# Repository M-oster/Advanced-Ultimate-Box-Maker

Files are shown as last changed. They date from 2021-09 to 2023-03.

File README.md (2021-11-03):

# Advanced Ultimate-Box-Maker

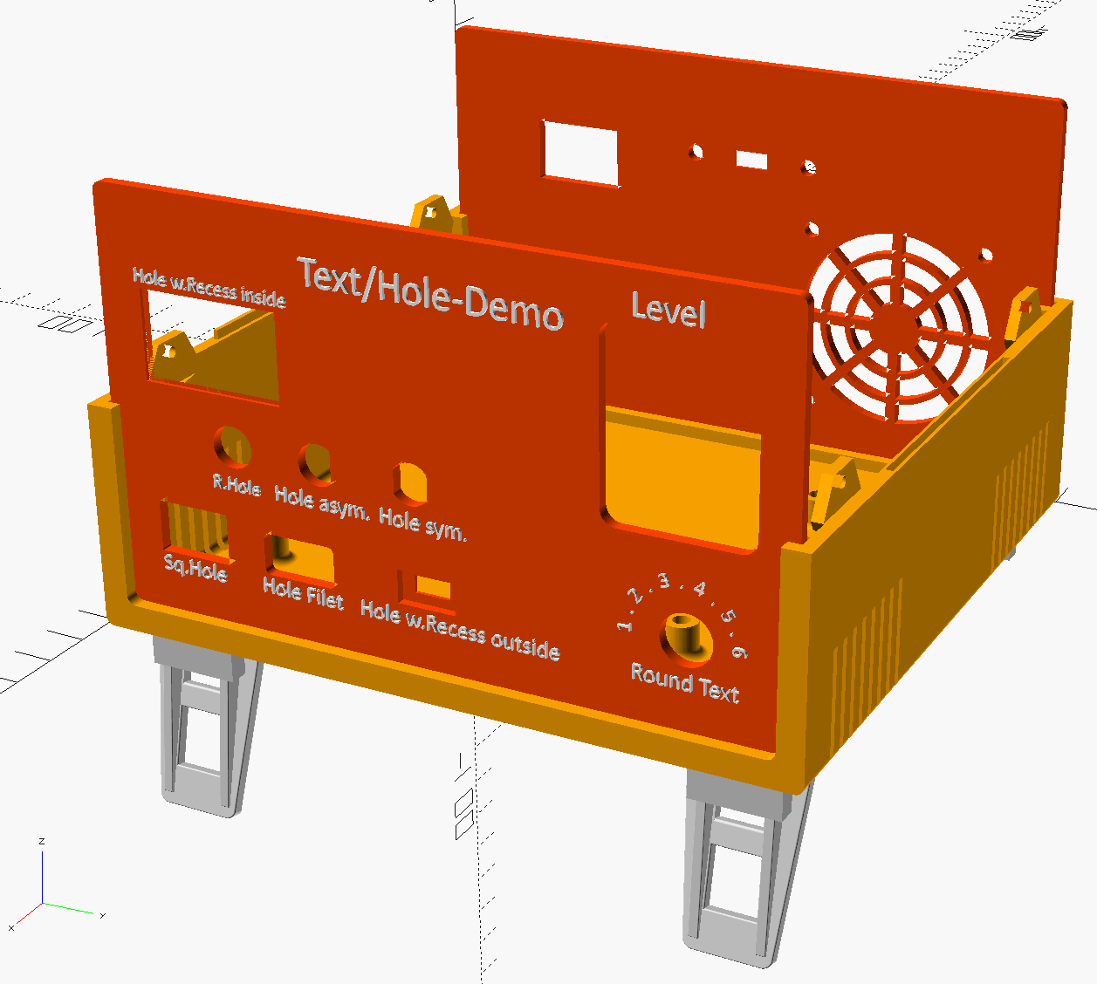
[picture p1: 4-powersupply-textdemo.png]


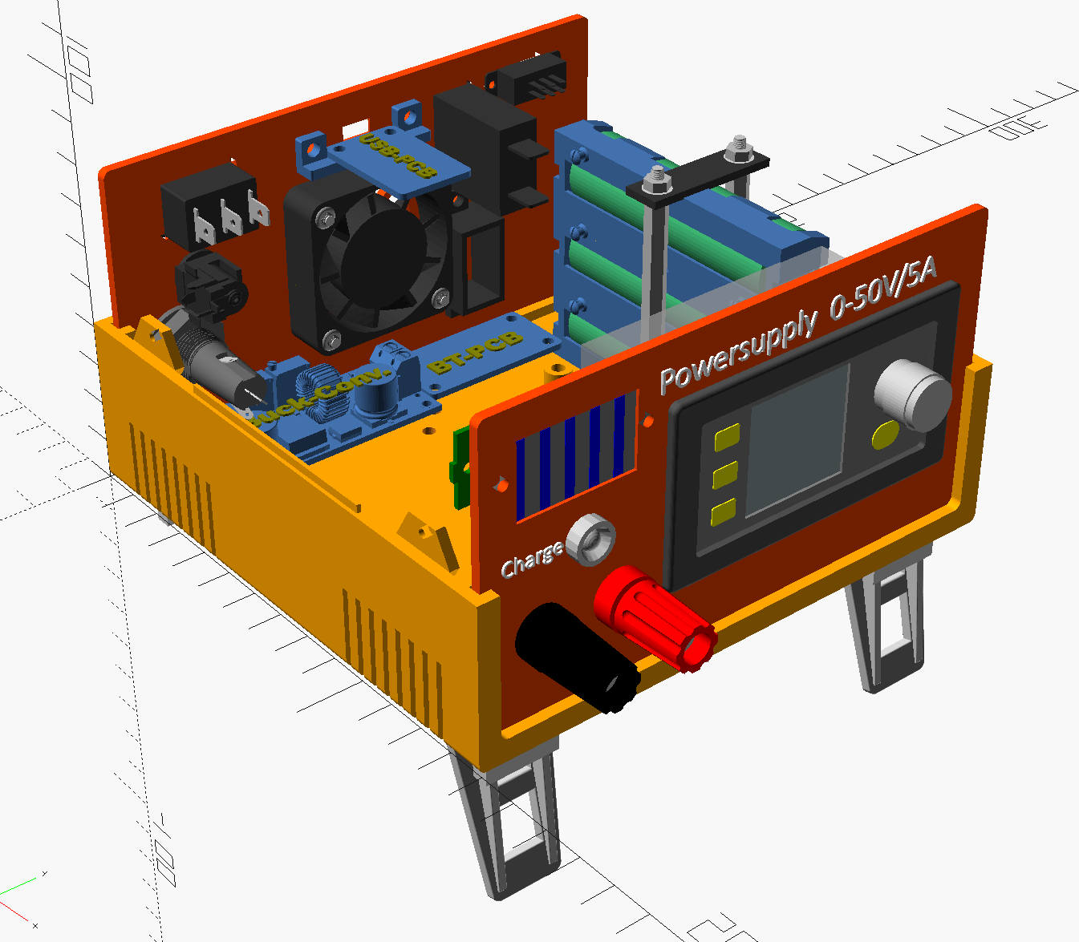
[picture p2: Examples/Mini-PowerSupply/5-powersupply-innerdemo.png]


## Introduction
For my projects in electronics I often need an appropriate housing. 
Commercial products have the disadvantage that they don’t fit exactly and cause a lot of work for manual drilling, cutting, adapting, etc.
I needed a software solution for creating an individual box using a 3D-printer.
* The software must have mainly a parametric design so that the properties of the box can be easily changed.
* The software must have a GUI for changing the parameters so that the program code does not need to be changed.
* Ideally the software allows to save the parameters in individual files.
* The software with the less disadvantages I could find, was OpenSCAD.
It is relatively easy to learn and has a so called customizer for changing and saving the parameters. But it has also a lot of restrictions to deal with. Despite this OpenSCAD was the first choice. My normally used CAD-Software “Fusion-360” is nice to use but has only a bit of a customizer.

For that reason, the decision was using OpenSCAD and I searched around which programs exists to solve my problem.
I found the “Ultimate Box Maker” with its forks and put me on to extend the features of these programs with help of some excellent libraries.
The result is this “Advanced Ultimate Box Maker”.

## Sources used in this advanced version
Originally box designs, used libraries and license
*	The original design was made by “Ultimate Box Maker” from Heartman www.thingiverse.com/thing:1264391 and http://heartygfx.blogspot.com
*	Great improvement to a PCB-based construction was made with the “Customizable revised Ultimate Box Maker”` from jbebel www.thingiverse.com/thing:2938921 and https://github.com/jbebel/Ultimate-Box-Maker.
*	The integration of a fan-guard was inspired by the “Customizable Fan Grill Cover”  from mightynozzle www.thingiverse.com/thing:2802474
*	use of the Library “BOSL2” from https://github.com/revarbat/BOSL2/
*	use of the Library “NopSCADlib” from https://github.com/nophead/NopSCADlib/
* `Programs are under license CC BY-NC 3.0 License and GNU General Public License 3`

## Requirements
1. OpenSCAD, download it from here: https://www.openscad.org/downloads.html
2. The library “BOSL2” from https://github.com/revarbat/BOSL2/
3. The library “NopSCADlib” from https://github.com/nophead/NopSCADlib
4. The actually “Advanced ultimate Box Maker” from here or thingiverse https://www.thingiverse.com/thing:4947863

## Installation
*	run the downloaded OpenSCAD-file and install the exe.
*	unpack the zip-file form BOSL2-library into the appropriate lib-directory (My Documents\OpenSCAD\libraries)
*	do the same with library-file “NopSCADlib”
*	The actually “Advanced ultimate Box Maker” from here.
Unpack the zip-file into the directory My Documents\OpenSCAD so that all files are in the sub-directory \Advanced-Ultimate-Box-Maker.
You have to create the directories without the Extension "-master" which github adds to the zip-files.

For checking of the installation, run the main-file “Advanced-Ultimate-Box-Maker-main.scad”, and press F5 within the GUI to create the basic box.

## Directory structure
the directory structure is inspired by the one from NopSCADlib.
But the project creating features are not used here, because its too much effort in the moment to additionally extend and adapt the code.

| Path | Contents |
|:-----|:---|
| `assemblies` | additional parts which are used for the box |
| `docs` | Documentation files, Schematics |
| `Examples` | Example projects with its own directories|
| `scad` | main scad file and associated scad files |
| `stls` | STL files for making printed parts |

## Features
Summary of Existing Features from the original version and the improved version:
*	Editable back- and front panel
*	Calculation of the box size from the PCB size and margin parameters
*	Horizontal or vertical text alignment arguments
*	Variable panel and tab thickness separate from the box
*	Square corners (no filet or chamfer)
*	Parameterize all dimensions, such that the box is infinitely scalable. Doubling every parameter will double the box in all dimensions.
*	Vents go through the floor and are scaled to fit the size of the filet.
*	For larger filets, scale interior filets to make exterior and interior filets concentric.
*	Decorations are optional
*	Box fixation tabs can individually be placed on the top or bottom shell

## Added more features to this Advanced version, list of the most important ones:
*	Allows to integrate the electronic parts of the NopSCADlib
*	Choice of different case feet (Hole,integrated feet, Rubber feet, Foldable feet)
*	Choice of different threated inserts for fixation tabs
*	Choice of different kind of PCB-feet (inserts, pillars, spacers)
*	Holes with a recess for front- or backpanel
*	Longholes for front- or backpanel
*	Customizable fan-guard for the backpanel
*	a lot of fan-sizes are integrated and their correct screw-distance is autom. choosen.
*	Ledges on both upper edges of the box shells for better stabilization
*	Allows to create extra holes in the bottom shell
*	Choose predefined textfont for paneltext
*	Frequent remarks added in the code and a lot of debug outputs can be activted

With this advanced version the number of program lines has grown from round about 900 to over 1800 lines.

## Handling the program
After starting OpenSCAD, you see the customizer on the right side with the various program values categorized in sections.
Click the center symbol   to view the hole box

### Sections and values
Sections and values in the customizer on the right windows side of the program:
These sections include several parametric values to adapt the box to the requirements in an easy way
and are generated from the appropriate code on the left side of the editor window.

### Different kind of values in the customizer
| Value | Description |
|:---|:---|
|Arrays, expression begins with “a..”|Cannot be changed in customizer.MUST be changed in the editor window on the left because of the customizers restrictions.
|Textbox| sets a text f.e.Front- or Backpanel. Change in customizer|
|Boolean Value|activates/deactivates an option. Change in customizer|
|Select field|selects a value out of a given list|
|Numeric value|can be changed in customizer|
All values, with exception of the arrays, can be saved in a configuration-file on top of the customizer window. The arrays must be saved with the complete scad-file (i.e. changing of the code)
 
One member in an array is the minimum, otherwise the program throws an error.
If the part is not used, array-members can be deactivated when On/Off-value is set to “0”.

### The most important values:
#### Section “box options”
| Section | Description |Remark|
|:---|:---|:---|
|PCBDraw| draws the PCB inside the box, labels it with text of “TextOnPCB”|	Array must be edited in code window.|
|aAddHoles|For adding holes in the bottom shell| for additional PCBs f.e.|
|PartsDraw|Draws electr. Parts with help of the NopSCADlib.| Parts must be imported and positioned in Module “ShowElectrParts”|
|Bar recess|Small ledge on top of Shells, can be activated/deactivated. |When Thick <2.5mm, recess is autom. deactivated because it cannot be printed|
|sTextFonts|Selection of the font for text on panels.| List contains windows-fonts and can be changed in code window. Font names must fit to the name in windows.|

#### Section “case feet”
| Section | Description |Remark|
|:---|:---|:---|
|CaseFeet|Various feet can be chosen (simple hole, Rubber feet, Foldable feet in 2 sizes)| The last both are created as stl-files and can be 3D-printed.|

#### Section “Box Fixation Tabs”
| Section | Description |Remark|
|:---|:---|:---|
|tab_inserts|Various kinds of fixations| simple holes for screws, threaded inserts|

#### Section “PCB Options”
With defining these variables the dimensions of the box are autom. calculated.
The value “TopMargin” defines in result the hight of the box.
The console window shows the result of the dimensions of the box.

#### Section “PCB Feet”
| Section | Description |Remark|
|:---|:---|:---|
|PCBFeet|Various kinds of PCB-feet, from simple holes for screws to holes with threaded inserts| All dimensions are autom. adapted|
Coordinates of the 4 PCB-feet:	The console window shows the resulting distances of the PCB-feet to prove the correct values of the PCB-holes.
If you enable “ShowExplanations” in the section ”Special Values”, the console window shows the position of the 4 PCB-feet.

#### Section “Frontplate Holes”
The variables within this section define 3 kind of holes. 
All these hole-parameters are Arrays and must be changed in the code window, not in the customizer.
| Section | Description |Remark|
|:---|:---|:---|
|aFP_Holes|	Defines round holes or longholes|There are 2 diams, diam1 and diam2. If both are equal, the result is a round hole. If diam1 > diam2 the result is a longhole,If sym=0, the hole is narrower on the right side.If sym=1, the hole is narrow on left ans right side|
|aFP_Sholes|Defines square holes
|aFP_SHolesRecess| 	Defines a recess of (PanelThick - Recess)|If Recess is positiv, its on the outer side. If recess is negativ, its on the inner side.

#### Section “Frontplate Text”
There are 2 kind of Texts. Normal text and round text.
All these hole-parameters are Arrays and must be changed in the code window, not in the customizer.
| Section | Description |Remark|
|:---|:---|:---|
|aFP_RTexts|	Defines round round text.| Useful for labeling Poti-values|
|aFP_STexts|	Defines normal text|

#### Section “Backplate Holes”, same as for Frontplate Holes

#### Section “Backplate Text”, same as for Frontplate Text

#### Section “Fan-guard settings”, only implemented for the Backplate
| Section | Description |Remark|
|:---|:---|:---|
|BP_fan_position|	Pos. of the fan-guard|can be activated by On/off-value set to “1”|
|Fan_size_in_mm|	List of fans are integrated in an array| When selecting a size, all parameters are calculated autom.|
|Screw_hole_diameter|	Diameter of the Fan-screw| M2, M3 or M4
|Fan_min_border_size|	The best fitting values are predefined.| Change them carefully|
|Fan_line_size| Size of pattern lines
|Fan_line_space| Space between two lines of the inner pattern	
|Number_of_support_lines|	Number of crosshairs for the fan-guard| 4 is a good value

#### Section “STL-element to export”
These Boolean values determine which part should be printed. `It makes sense to enable only one part.`
With keys F5, then F6, you can render a part for STL-Export.
Export the part with key F7 and save it as STL-file.
| Section | Description |Remark|
|:---|:---|:---|
|TShell|	Top shell of the box|
|BShell|	Bottom shell of the box|
|FPanl|	 Frontpanel|
|BPanel| Backpanel|
|SmallParts|Small assembly-parts which should be printed|It depends what you have choosen, f.e. can be spacers for the PCB.

#### Section “Special values”
| Section | Description |Remark|
|:---|:---|:---|
|ShowExplanations|	Self defined echo-outputs in the console-window|They are defined in the “MyExplanations.scad” file. f.e.the position of the 4 PCB-feet
|Debug|	When “1”, there is a lot of echo output from program-values|For easier assignment, the output has prefixed.<mod.>: from which module the output comes.<decription>: name of the variable or its description

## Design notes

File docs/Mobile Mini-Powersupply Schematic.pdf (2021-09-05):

Module view of the Powersupply

## Module view of the Powersupply

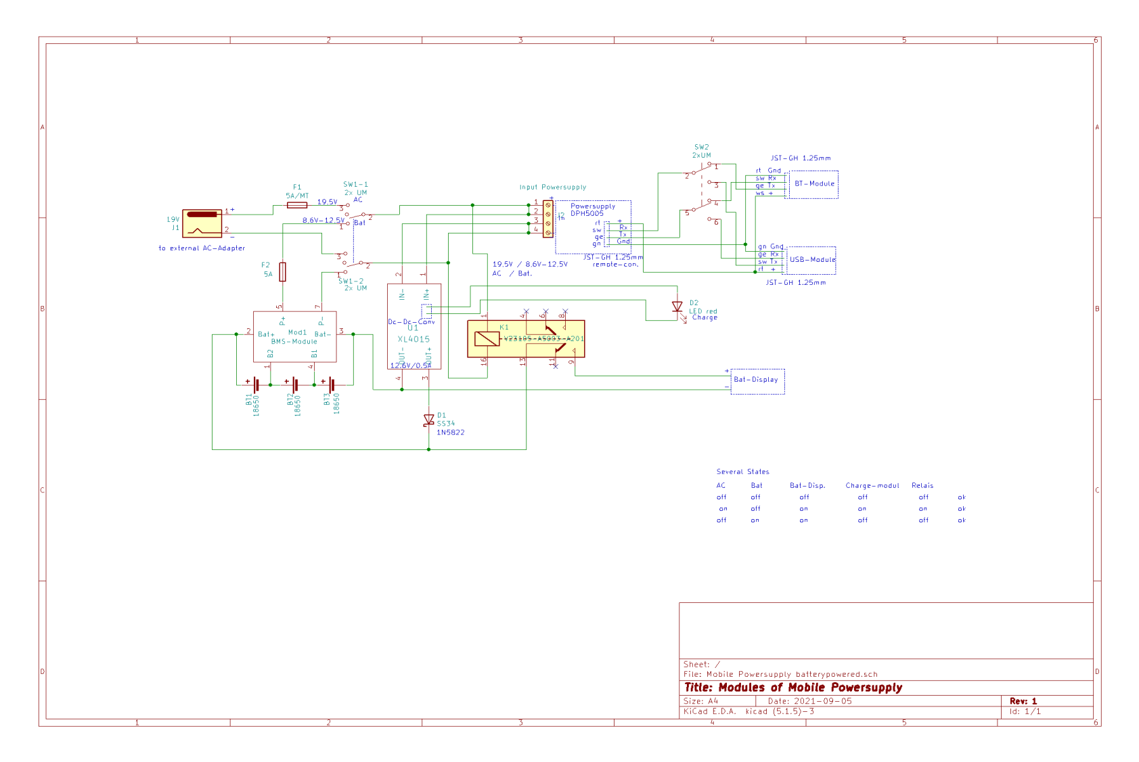
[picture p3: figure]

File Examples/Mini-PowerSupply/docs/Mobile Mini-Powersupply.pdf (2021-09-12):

# Mobile Mini-Powersupply

# Electronic

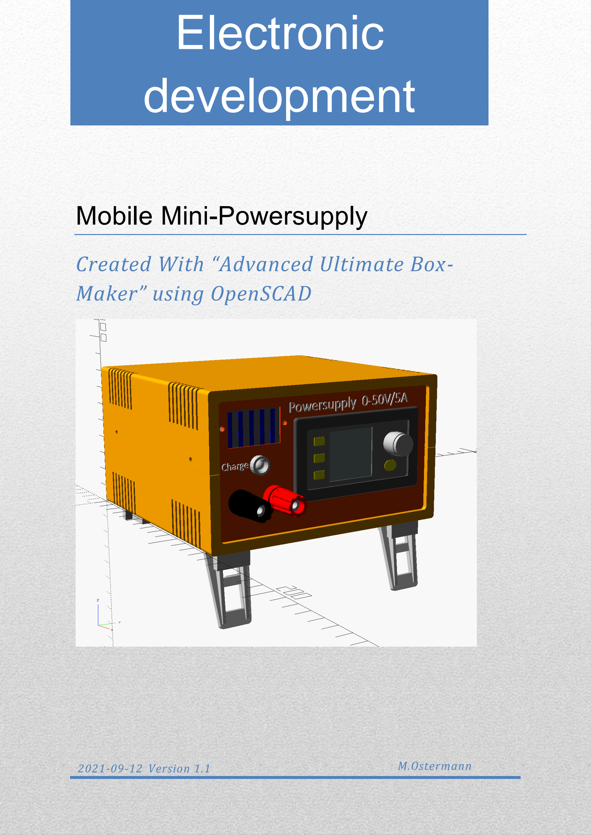
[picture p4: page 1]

Introduction

# Created With “Advanced Ultimate Box-Maker” using OpenSCAD

2021-09-12 Version 1.1

# development

M.Ostermann

# Mobile Mini-Powersupply

1

## Table of contents

Introduction | 0
Main design aspects of the DIY Powersupply | 0
The “Advanced Ultimate Box-Maker” with OpenSCAD | 0
Features of the Powersupply | 0
Explanation of the parts | 1
Buck-Boost converter DPH-5005 from Ruideng | 1
Li-ion charger module | 1
Protection module for batteries (BMS) | 1
AC-adapter with 19V / 4.5A | 1
3x Li-Ion battery cell 18650 | 1
Module view of the Powersupply | 0
Bill of Materials (BOM) | 0
Handling of the Powersupply | 0
The power switch | 0
Connections on the backside | 0
Additional work to do | 1
External LED for charge state | 1
Additional rubber feet for foldable feet | 1

Introduction

## Introduction

For my projects in electronics I often need an appropriate housing.
Commercial products have the disadvantage that they don’t fit exactly and cause a lot of work for manual drilling, cutting, adapting, etc.
I needed a software solution for creating an individual box using a 3D-printer.
- The software must have mainly a parametric design so that the properties of the box can be easily changed.
- The software must have a GUI for changing the parameters so that the program code does not need to be changed.
- Ideally the software allows to save the parameters in individual files.
The software with the less disadvantages I could find, was OpenSCAD.
It is relatively easy to learn and has a so called customizer for changing and saving the parameters. But it has also a lot of restrictions to deal with. Despite this OpenSCAD was the first choice. My normally used CAD-Software “Fusion-360” is nice to use but has only a bit of a customizer.

For that reason, the decision was using OpenSCAD and I searched around which programs to create boxes exists to solve my problem.

I found the “Ultimate Box Maker” with its forks and put me on to extend the features of these programs with help of some excellent libraries.
The result is this “Advanced Ultimate Box Maker”. (see the appropriate Docu)

Main design aspects of the DIY Powersupply
- The powersupply should be rather cheap and easy to build.
- It should consist of ready to use modules.
- Powersupply should be powered by chargeable batteries or external AC-adpater.

## The “Advanced Ultimate Box-Maker” with OpenSCAD

For Description of the features, the installation and how to use the software please read the paper “Advanced ultimate-Boxmaker”

Features of the Powersupply
- Outputvoltage 0-50V up to max.5A ( in AC-Mode)
- Constant current, Constant Voltage (CC, CV)
- Switchable operation between AC-Adapter and battery

Explanation of the parts

1

- Battery-Indicator
- Autom. battery charge during AC-operation
- Remote control over Bluetooth with smartphone app or USB PC-App

## Explanation of the parts

Buck-Boost converter DPH-5005 from Ruideng It is a ready-to-use kit from china. It has 4 modules:
- The converter itself
- the control-panel with the display
- Add. Consists of an USB-interface and
- Bluetooth-Interface for remote control of the powersupply.

Li-ion charger module
Charging module (3S) for charging the three 18650 cells during AC-mode. Charges the cells with 0.5A and has a charge cuttoff voltage of 12.6V.

Protection module for batteries (BMS)
This module protects the batteries in several manner:
- Overvoltage during charging
- Undervoltage during discharging
- Overcurrent protection for discharging

AC-adapter with 19V / 4.5A
The AC-adapter is switchable between 12V – 24V. 19V is the recommended voltage output.

3x Li-Ion battery cell 18650
Samsung INR18650-25R 2500mAh cells without protection

Module view of the Powersupply

## Module view of the Powersupply


Bill of Materials (BOM)

## Bill of Materials (BOM)

The parts are rather cheap and the source of supply is mostly in china and ebay
Description | | price
DPH5005 Buck-boost converter with USB- and BT-communication | https://de.aliexpress.com/item/32840324731.html without USB/BT-modules | 47€-40€
XL4015 5A DC-DC Step Down converter | https://www.ebay.de/itm/402597361624 or https://www.aliexpress.com/item/32891328430.html | 3,70€ or 2,30€
(270g/93m Filament 1.75mm PLA grey | | ~5,00€)
Axicom D2N12-960Relay DPDT (2xUM) V231005-A5003-A201 | Kessler electronic https://www.ebay.de/itm/111447113032 | 2,30€
BatteryIndicator LEDdisplay | Naltronic https://www.ebay.de/itm/123571387480?var=424142377263 or https://www.aliexpress.com/item/1005002375550407.html | 5,80€ or 2,80€
Battery-BMS, BalanceBoard, 6A-8A max Mesacomponents | https://www.ebay.de/itm/254159873534?var=553510124474 or https://www.aliexpress.com/item/4000385806747.html | 9,90€ or 2,30€
Switch On-off-on Wippschalter Ein-Aus-Ein | https://www.aliexpress.com/item/32967528231.html or https://www.ebay.de/itm/264813617899 | 2,20€ or 6,00€
Submini slide switch DPDT (Schiebeschalter 2xUM) | Kessler electronic https://www.ebay.de/itm/311859237255 | 1,00€
Powerplug High-Amp Switchcraft SC1943-ND | Digikey https://www.digikey.com/en/products/detail/switchcraft-inc/S1017/3909312 | 7,00€
Threated inserts M3x6g Gewindeeinsätze M3x6g (gegenläufig) | Msr-coptertools https://www.ebay.de/itm/173779404364 | 6,00€
Fuse-Holder Sicherungshalter Snapin SH8 | Centralsystems-isp https://www.ebay.de/itm/284368894849 | 3,55€
Fuse-Holder incl Si. 5A , 5x20mm, 12mm° | https://www.ebay.de/itm/173575874739 | 3,50€
Schottky-Diode 1N5822 | https://www.ebay.de/itm/254069873397 | 3,00€
Kfz-Flachsicherungen 10A | https://www.ebay.de/itm/233933295008 | 2,50€
Laptop AC-Adapter 12V-20V / 4.5A (19V-20V) | Flystorefly https://www.ebay.de/itm/402696857628 | 18,20€
Akkuhalter (Batteryholder) for 3 18650 cells | https://www.ebay.de/itm/174814565327 | 4,50€
Fan (Lüfter) 40mmx10mm, 5V, 2-pol | https://www.ebay.de/itm/384372531353 | 5,00€
LED with socket | https://www.ebay.de/itm/164496995162 | 2,75€
| Amount, (Summe) | 112€ -137€

Handling of the Powersupply

## Handling of the Powersupply

The power switch
The main power switch is on the backside and has three positions:
- the middle position is the off-postion. Powersupply is turned off.
- in postion “Bat” the device works in battery mode. It uses the internal battery-cells.

be careful, not to draw more than 4 A from the cells for a longer time. The batteries heat up and because battery socket is made of plastic, the contact springs expand. That will cause contact problems to the batteries.

To avoid this, you must use nickel stripes and a spot welder instead of sockets for connecting the batteries.
- In postion “AC” the external AC-Adapter must be connected. The batteries are autom. charged and the powersupply can deliver more current.
Batteries cannot be overcharged, the charge process is automatically completed.

Connections on the backside

Power switch Remote switch USB or BT Battery Fuse

USB for remote Ctrl

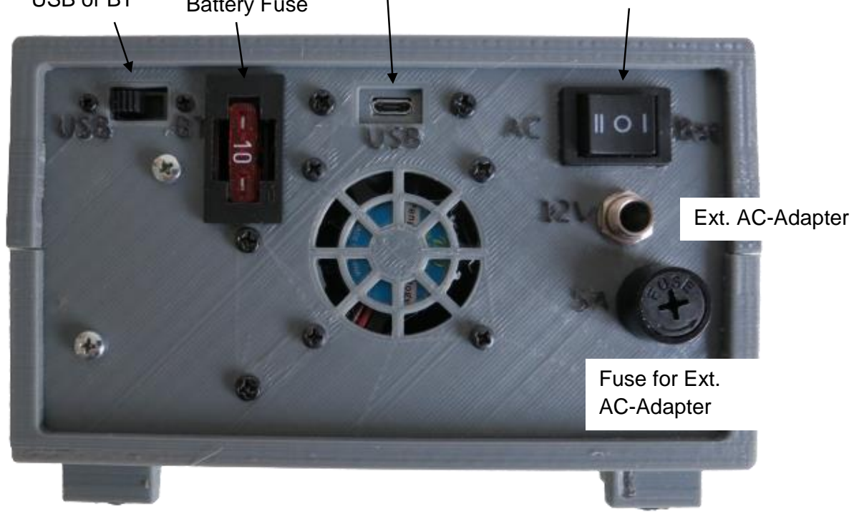
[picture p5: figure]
Ext. AC-Adapter; Fuse for Ext. AC-Adapter

Explanation of the parts

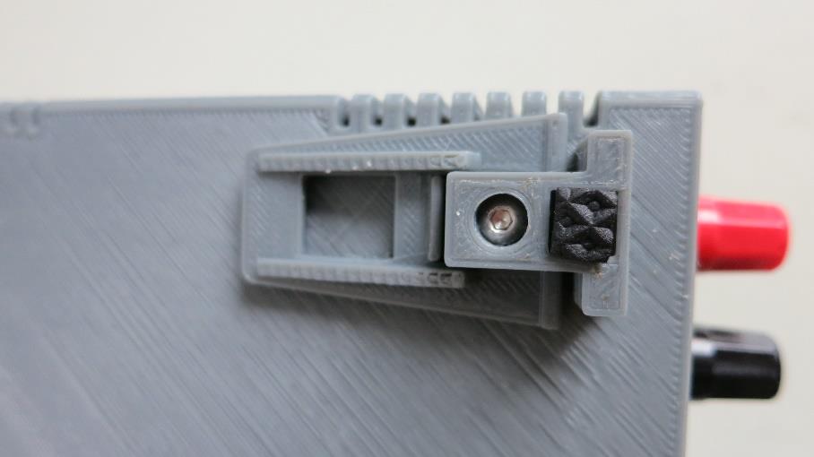
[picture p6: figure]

1

## Additional work to do

External LED for charge state
The small red LED on the PCB of the charge module ha to be desoldered for connecting the external LED.
Desolder the LED and solder two wires on the small pads.
On the other end solder these two wires to the external red LED.
Pay attention to the polarity of the LED. Don’t use another LED color.

Additional rubber feet for foldable feet
To prevent the powersupply form sliding over the ground the some rubber-feet can be added into the recess of the foldable feet.

But it must be self-adhesive rubber material not spongue rubber. That’s too soft.

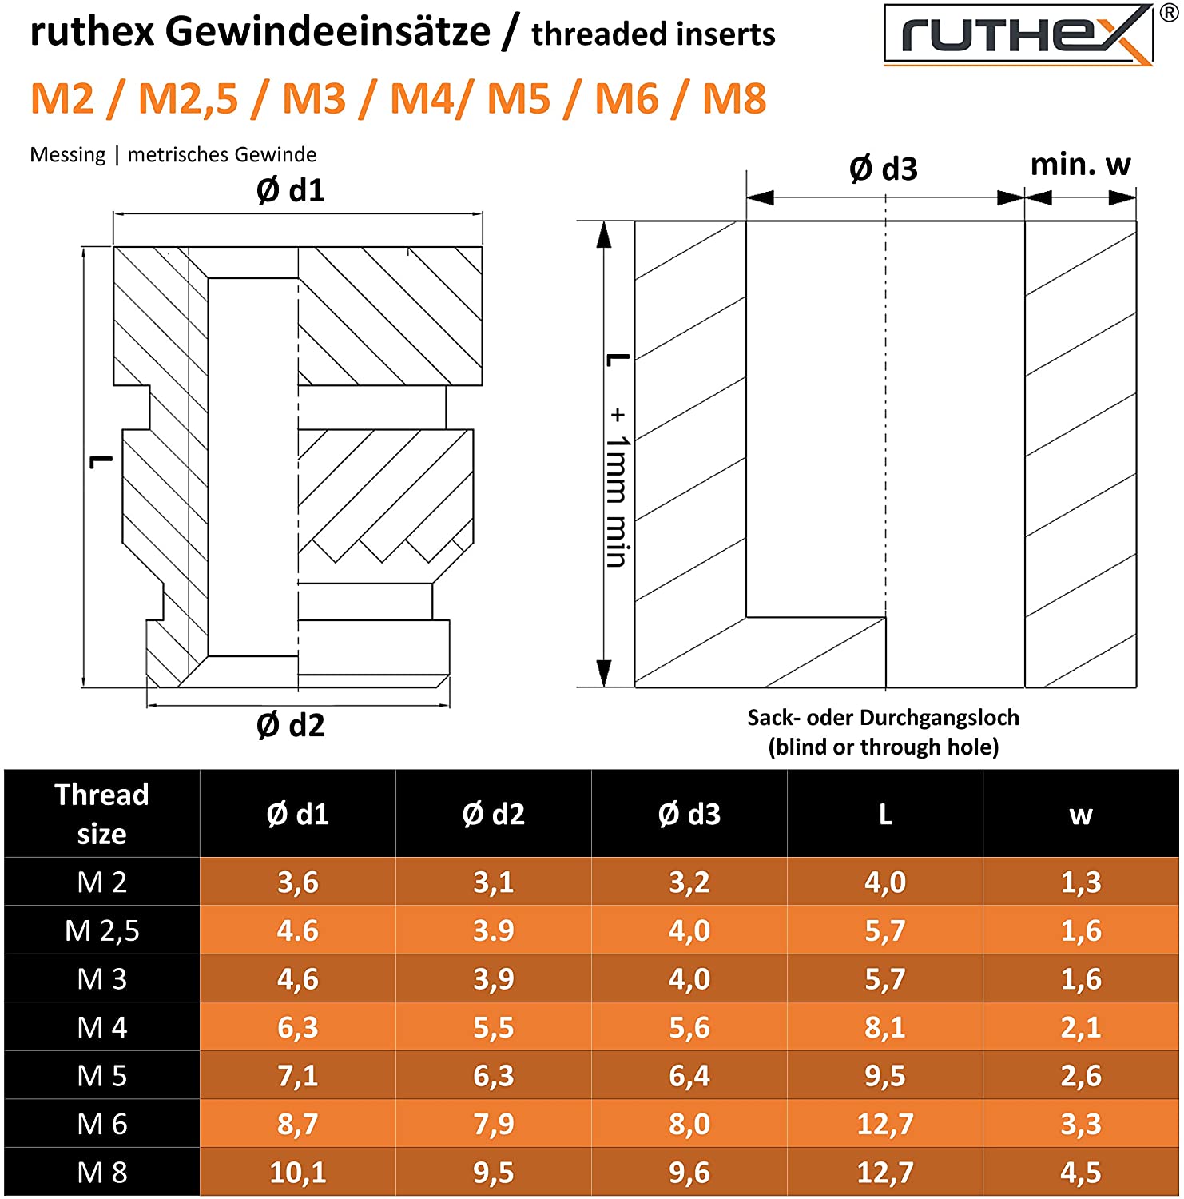
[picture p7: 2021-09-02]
Examples/Mini-PowerSupply/docs/Ruthex Inserts.jpg

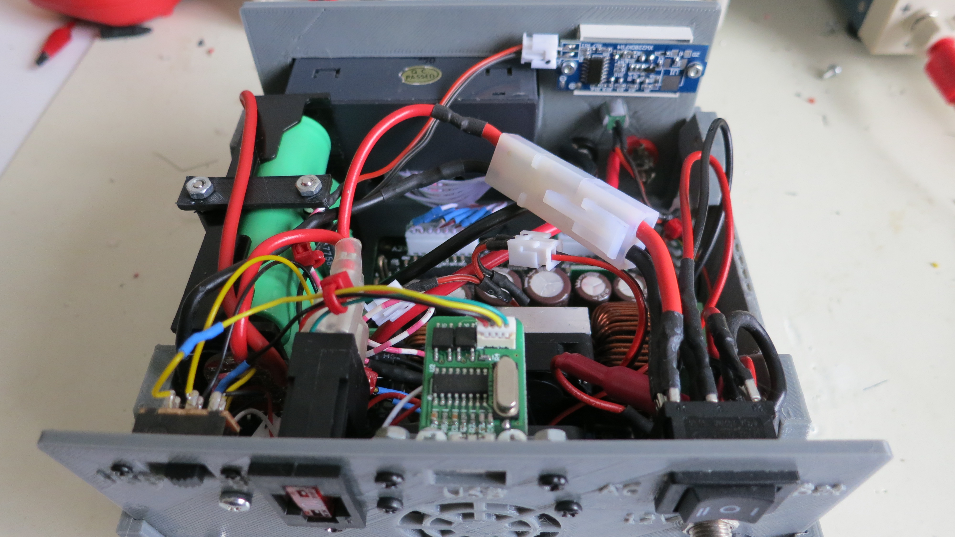
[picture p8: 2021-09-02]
Examples/Mini-PowerSupply/7-powersupply-innerview.JPG

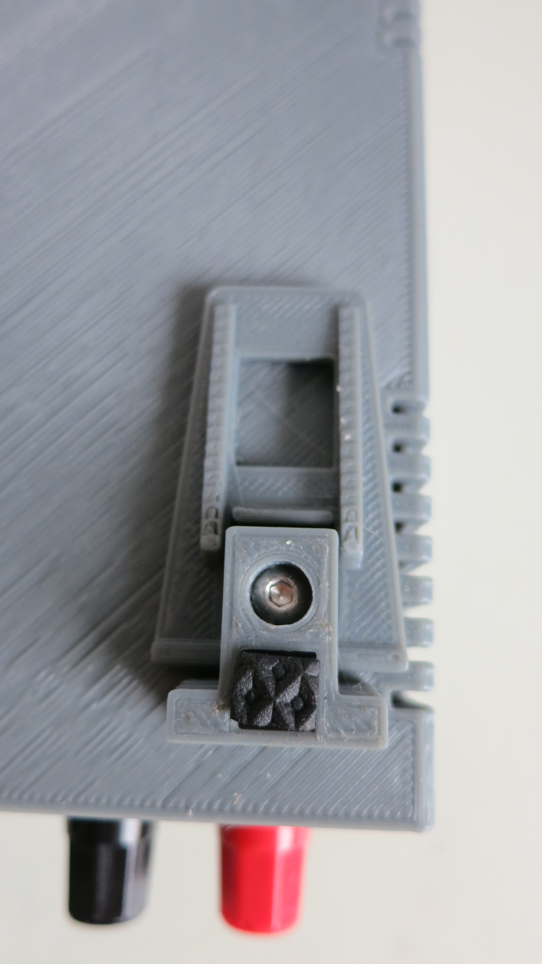
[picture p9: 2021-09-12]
Examples/Mini-PowerSupply/9-foldable fet-underside.JPG

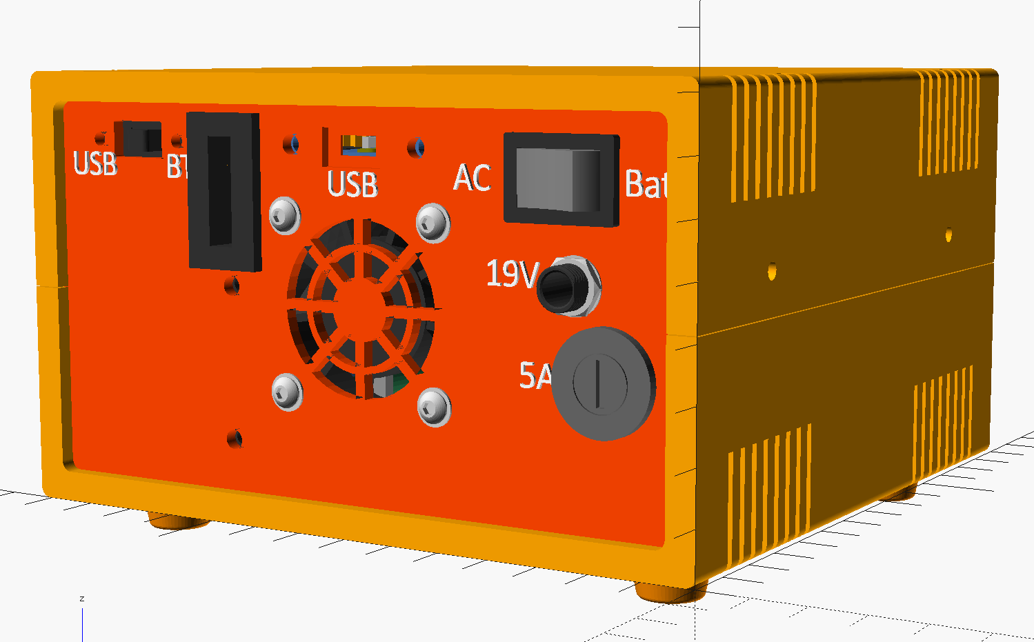
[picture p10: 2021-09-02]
Examples/Mini-PowerSupply/3-powersupply-backview.png

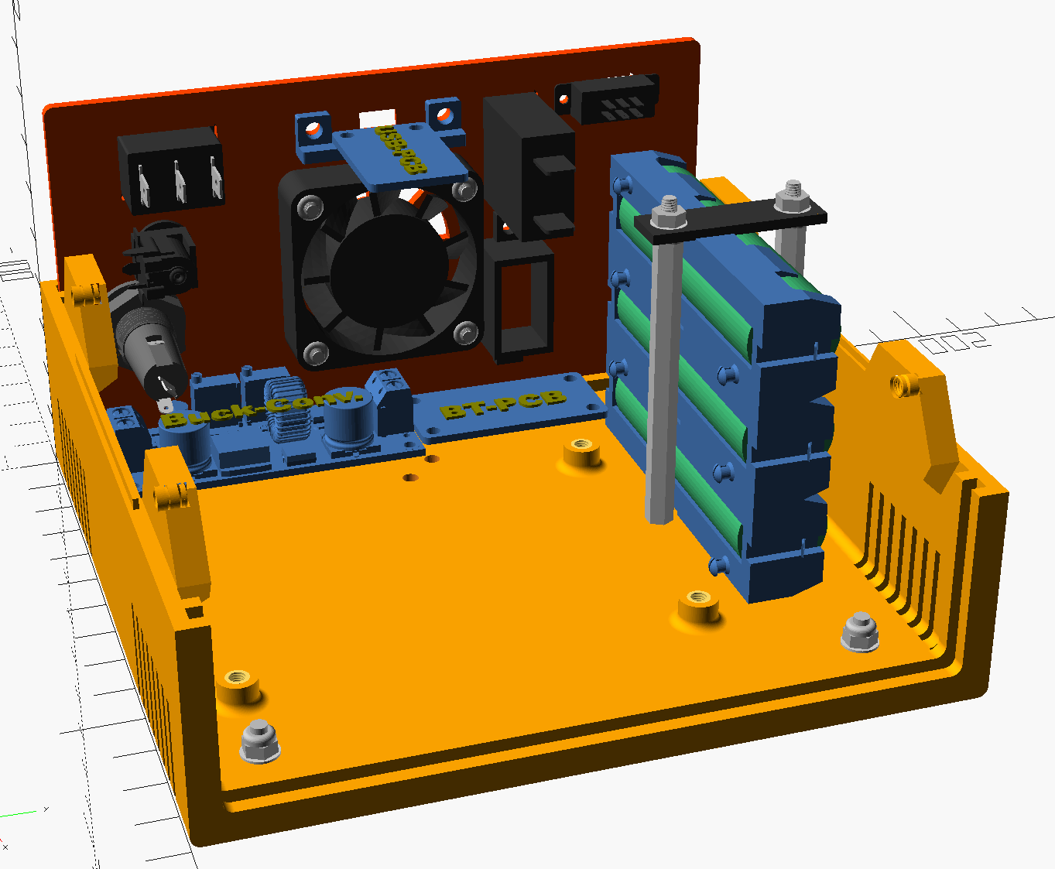
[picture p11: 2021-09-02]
Examples/Mini-PowerSupply/6-powersupply-innerdemo.png

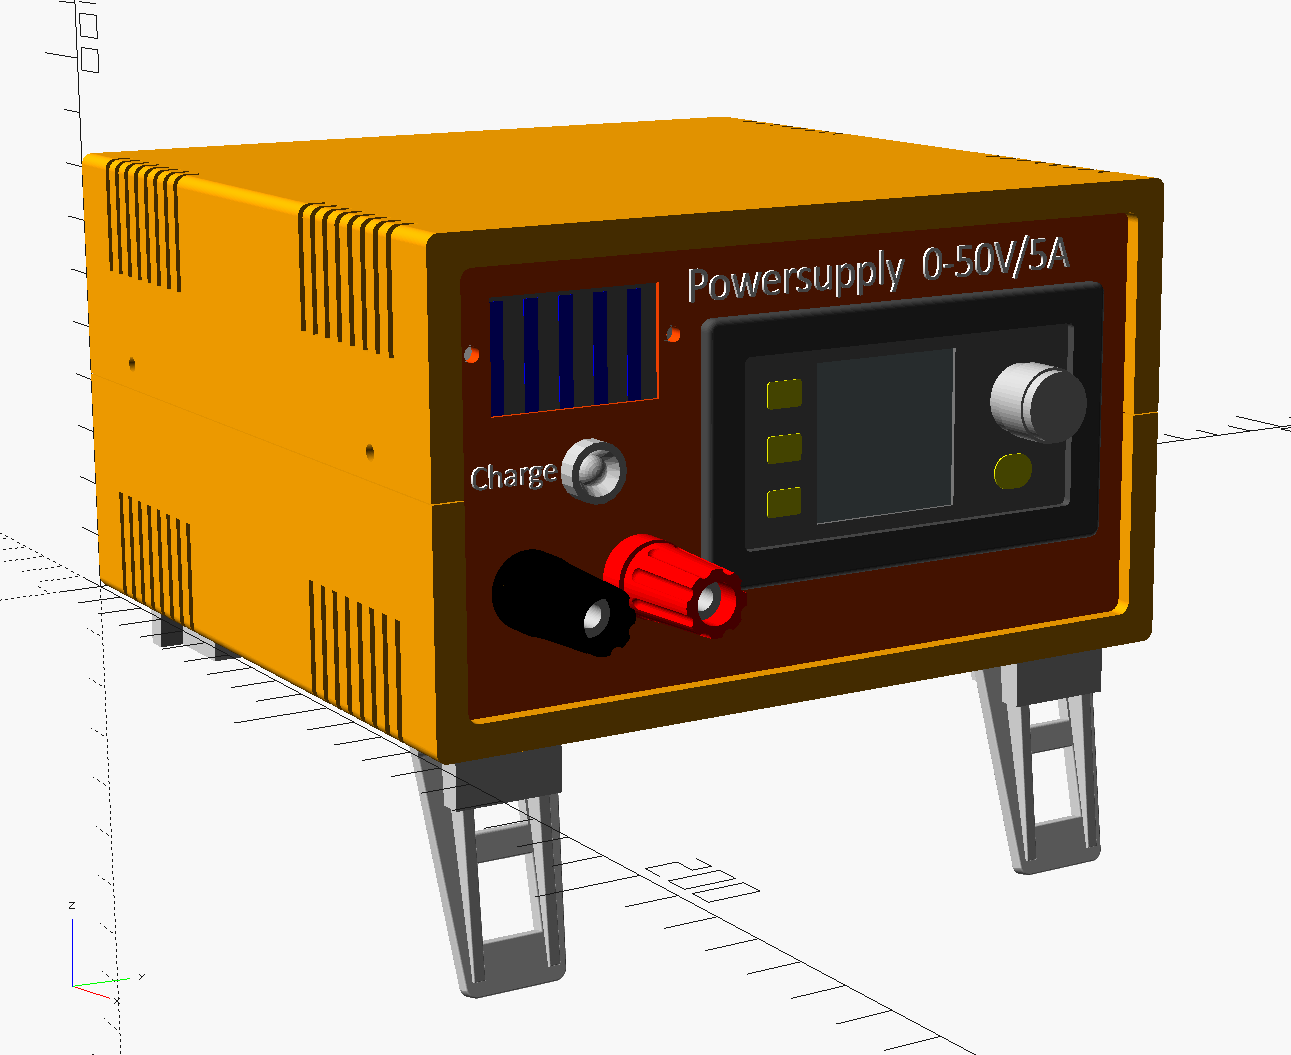
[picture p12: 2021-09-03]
Examples/Mini-PowerSupply/1-powersupply-front-full.png

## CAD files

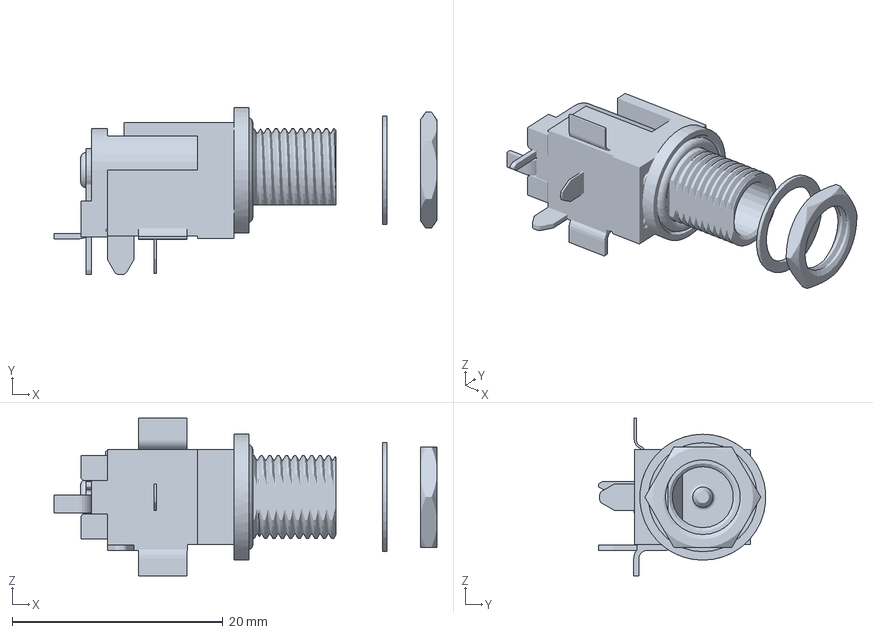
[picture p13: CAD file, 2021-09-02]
Examples/Mini-PowerSupply/assemblies/powerJack-complete.amf
36.3 x 15.9 x 14.9 mm

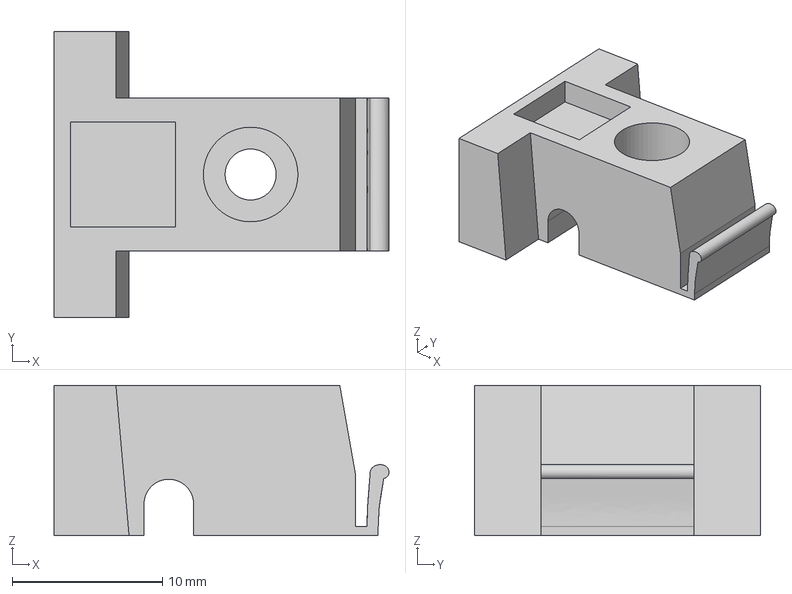
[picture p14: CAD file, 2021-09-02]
assemblies/FoldingFoot-base-small.step
22.3 x 19.1 x 10.0 mm

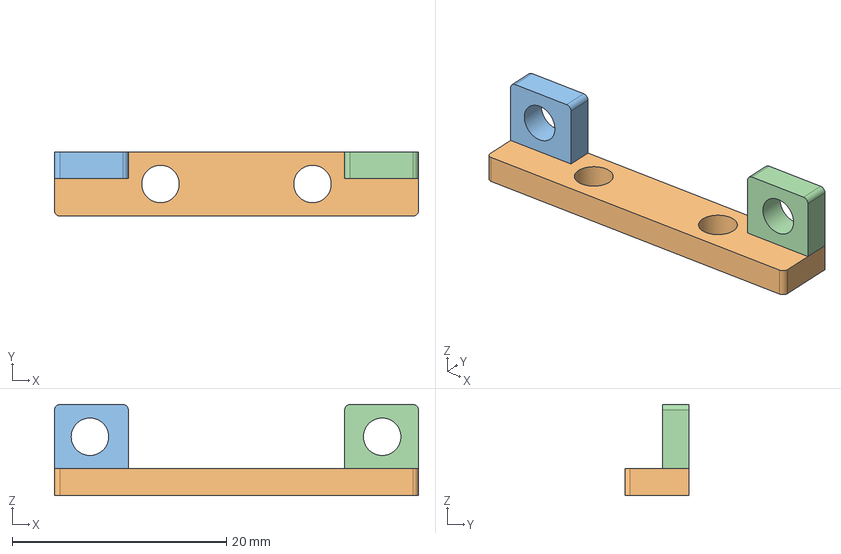
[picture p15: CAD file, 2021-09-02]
Examples/Mini-PowerSupply/assemblies/USB-Holder.step
34.0 x 6.00 x 8.50 mm

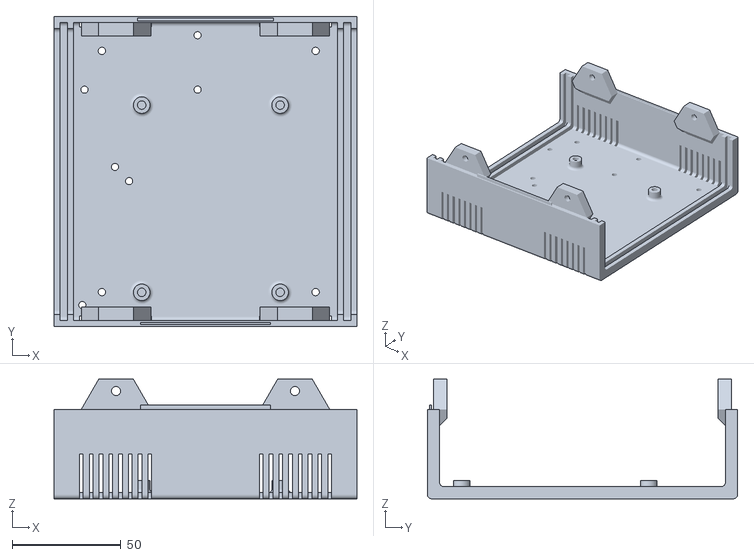
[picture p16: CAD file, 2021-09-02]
Examples/Mini-PowerSupply/stls/Adv-Ultimate-Box-PowerSupply-BottomShell.stl
139.2 x 142.6 x 54.9

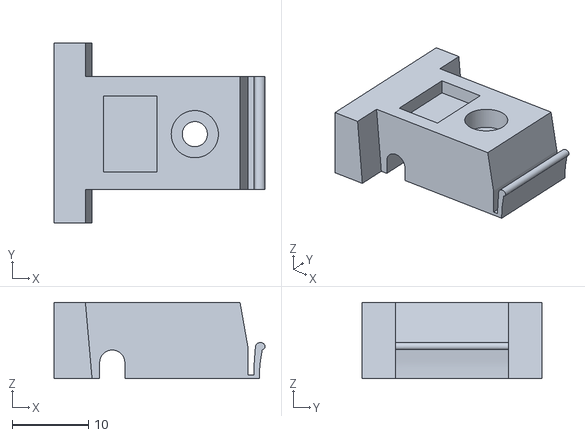
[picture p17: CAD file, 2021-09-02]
stls/FoldingFoot-base.stl
27.7 x 23.7 x 10.0

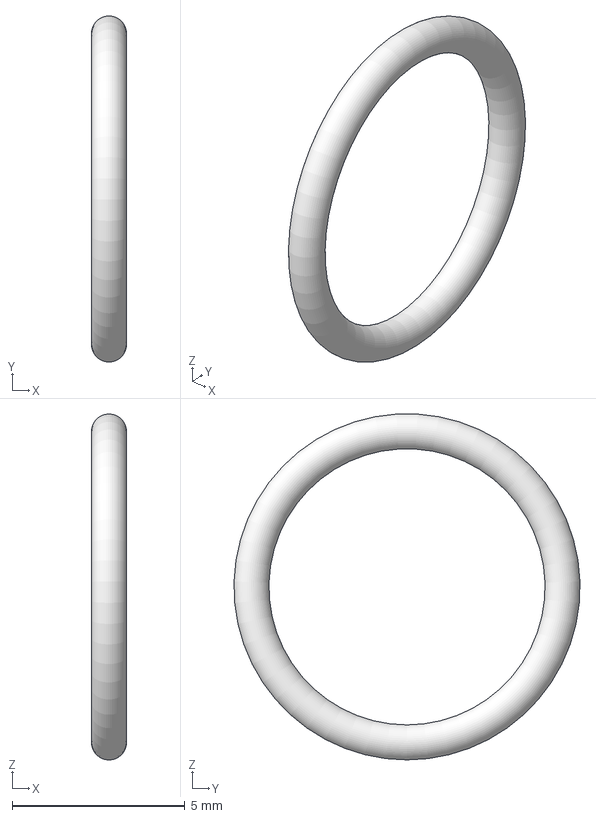
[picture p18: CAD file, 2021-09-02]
Examples/Mini-PowerSupply/assemblies/PowerJackRing.step
1.02 x 10.0 x 10.0 mm

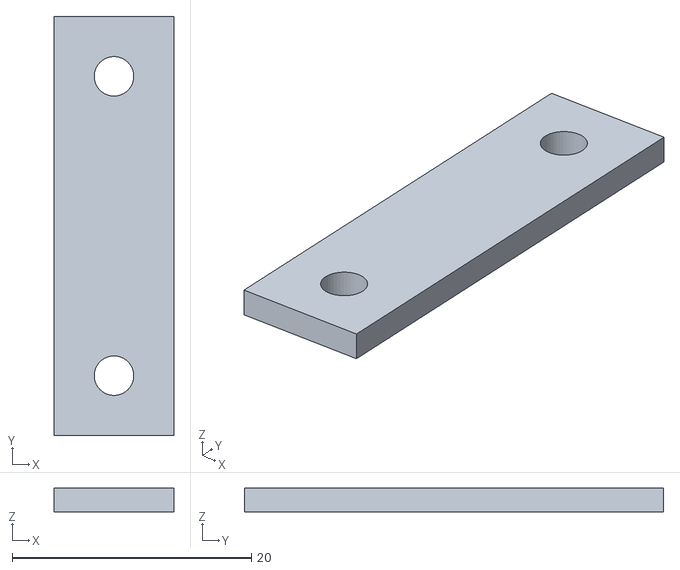
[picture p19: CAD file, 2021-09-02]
Examples/Mini-PowerSupply/stls/BatteryHolder.stl
10.0 x 35.0 x 2.00

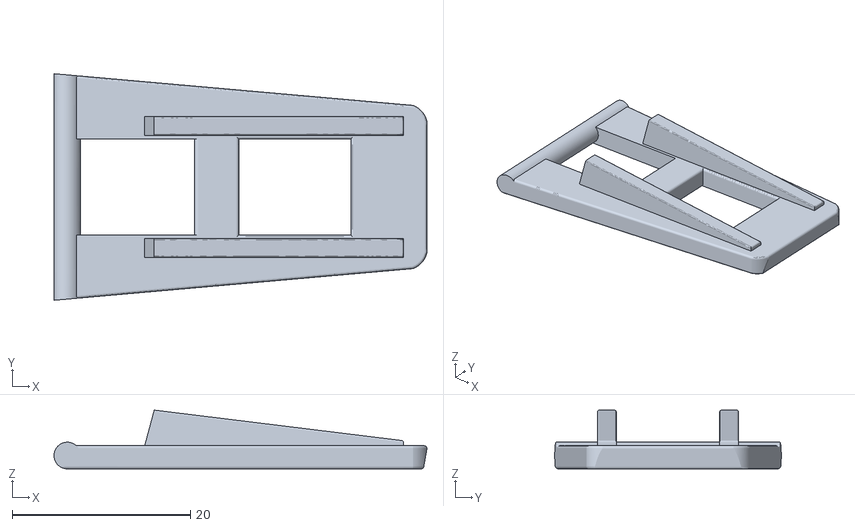
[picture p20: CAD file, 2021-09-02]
stls/FoldingFoot-arm-small.stl
41.9 x 25.5 x 6.60

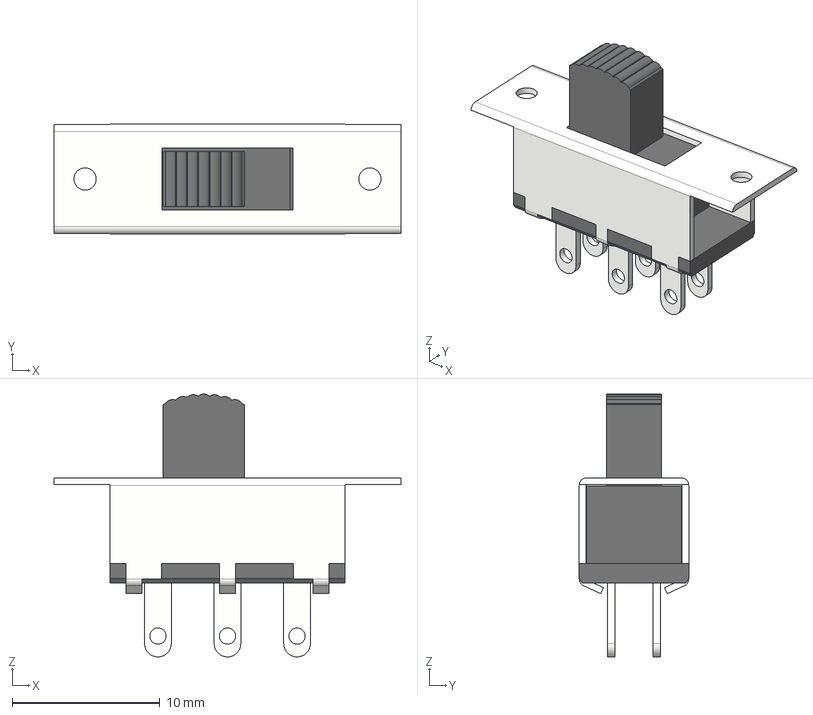
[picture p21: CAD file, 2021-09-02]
Examples/Mini-PowerSupply/assemblies/DPDT_Slide_Switch.step
23.4 x 7.40 x 17.8 mm

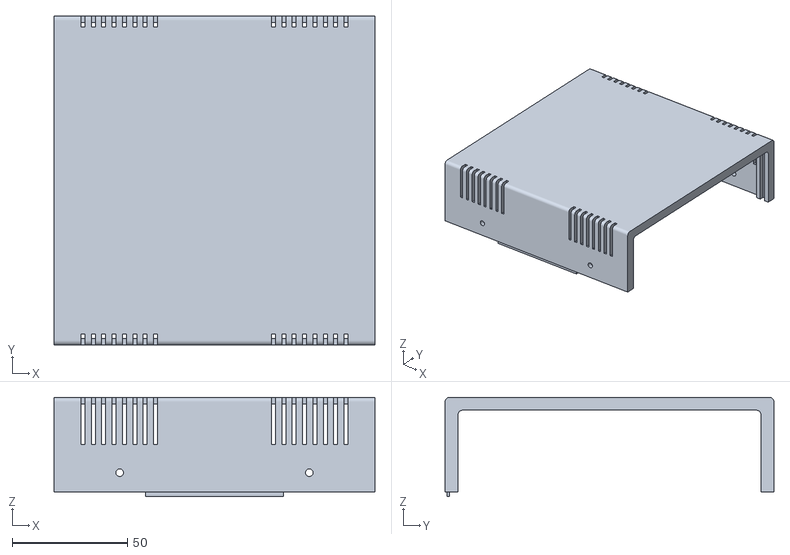
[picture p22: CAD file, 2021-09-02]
Examples/Mini-PowerSupply/stls/Adv-Ultimate-Box-PowerSupply-TopShell.stl
139.2 x 142.6 x 43.1

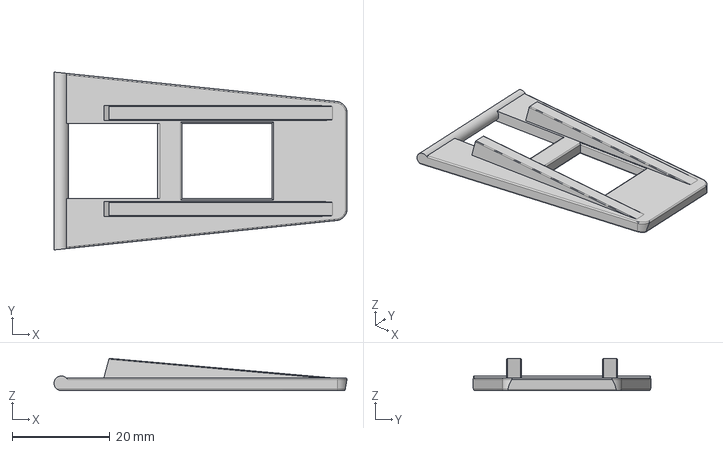
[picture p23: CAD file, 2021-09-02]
assemblies/FoldingFood-arm.FCStd
59.9 x 36.4 x 6.60 mm

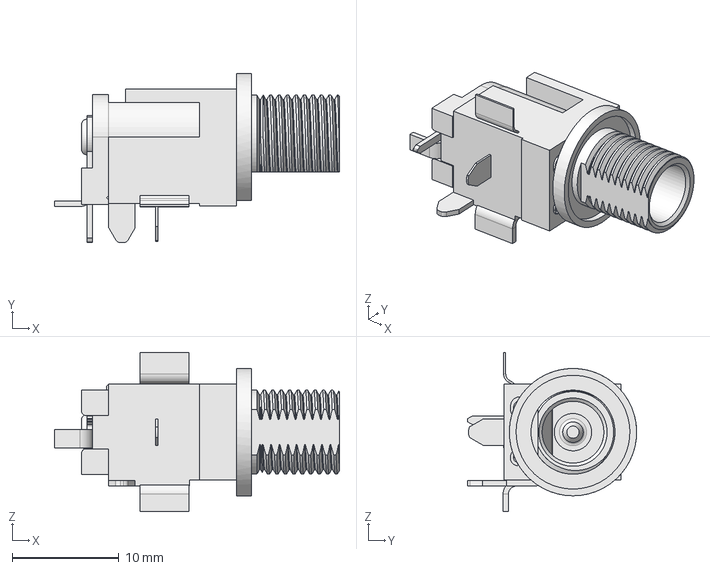
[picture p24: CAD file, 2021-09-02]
Examples/Mini-PowerSupply/assemblies/PowerJack.step
26.7 x 15.9 x 14.9 mm

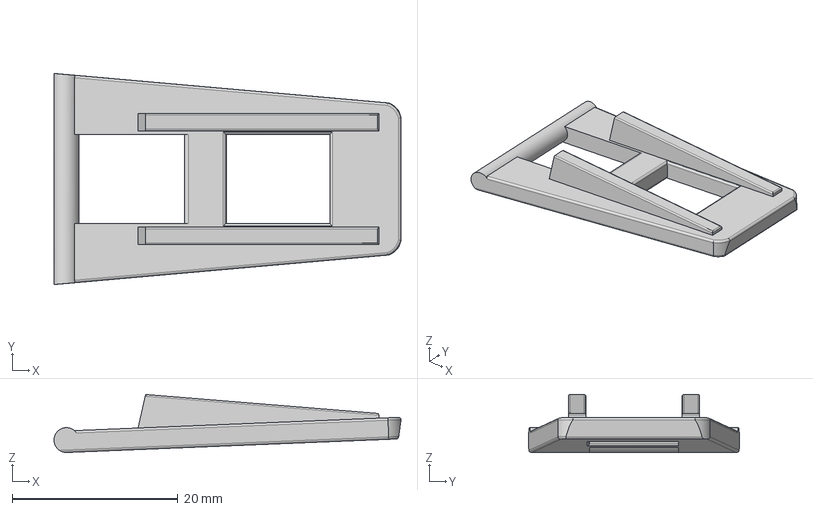
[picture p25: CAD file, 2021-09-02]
assemblies/FoldingFood-arm-small.FCStd
41.8 x 25.5 x 7.00 mm

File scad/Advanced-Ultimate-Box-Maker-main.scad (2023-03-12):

include <BOSL2/std.scad>

include <NopSCADlib/core.scad>

include <MyTubings.scad>
include <MyPCBPillars.scad>
include <MyInserts.scad>
include <MyComponents.scad>
include <MyRockers.scad>
include <MyExplanations.scad>






/* Box design originally by:
////////////////////////////////////////////////////////////////////
              -    FB Aka Heartman/Hearty 2016     -
              -   http://heartygfx.blogspot.com    -
              -       OpenScad Parametric Box      -
              -         CC BY-NC 3.0 License       -
////////////////////////////////////////////////////////////////////

////////////////////////////////////////////////////////////////////
Improved by jbebel:
http://github.com/jbebel/Ultimate-Box-Maker

To create a box, start by modifying the numerical parameters in the sections
below. This can be accomplished using a release of OpenSCAD newer than 2015.03.
As of the time of writing, this means that a development snapshot is required.
The Thingiverse Customizer may also potentially work, but at the time of
writing, it was inoperable.

The simplest choice is to hand-edit the .scad file. Feature toggles are
annotated with a comment. The other numerical parameters are measurements in
mm. Everything is parametrized, so if you double all the non-feature parameters
you will double the box size in every dimension. Certain parameters are derived
from other parameters. If you wish to override them, you may, but sensible
defaults have been chosen. Notably the design in this revision is particularly
PCB-centric, in that you should start with your PCB size and adjust the margins
around it to determine the box size. If you care more about the box size, you
can set the Length, Width, and Height explicitly, but read the comments around
them.

Once your box is sized appropriately, you can use the Panel modules to design
the holes and text for the front and back panels. Helper variables are provided
to assist you in positioning these holes relative to the PCB, if your holes are
for PCB-mounted components.

When you are ready to print, adjust the values in the "STL element to export"
section, and export each part one at a time.

Experimental options are provided for a screwless design, but these are
untested. In particular, the box fixation tabs may need thicknesses adjusted
in order to have the appropriate flexibility.

////////////////////////////////////////////////////////////////////

////////////////////////////////////////////////////////////////////
extended by m-oster
http://github.com/M-oster/Advanced-Ultimate-Box-Maker

________________________________________________________


*/

// preview[view:north east, tilt:top diagonal]
//----------------------- Box parameters ---------------------------

/* [Box options] */
// - Wall thickness
Thick = 2.8;//[2.0:0.1:5.0]
// - Panel thickness
PanelThick = 2.5;
// - Font Thickness
FontThick = 0.6;
// - Filet Radius
Filet = 2;
// - 0 for beveled, 1 for rounded
Round = 1; // [0:No, 1:Yes]
// - Printer margin around interior cutouts
CutoutMargin = 0.3;
// - Margin between mating parts
PartMargin = 0.1;
// - Draw PCB
PCBDraw = 1; //[0:No, 1:Yes]
// - Text on PCB
TextOnPCB="PCB";
// - Draw Electronic Parts
PartsDraw = 0; //[0:No, 1:Yes]
// - Decorations?
Decorations = 1; // [0:No, 1:Yes]
// - Decorations to ventilation holes
Vent = 1; // [0:No, 1:Yes]
// - Decoration-Holes width (in mm)
Vent_width = 1.7;  //1.5
// - Tolerance (Panel/rails gap on one edge)
PanelThickGap = CutoutMargin + PartMargin;      // +0.4
PanelVerticalGap = PartMargin;                  // +0.1
PanelHorizontalGap = CutoutMargin + PartMargin; // +0.4
// - Bar/Recess on upper edge of bottom/top-shell (if Thick >= 2.5)
bar_recess = 1; //[0:No, 1:Yes]
// - Additional Holes - [OnOff,xPos,yPos,diam]
aAddHoles = [[0,54,103,3]];
//           Add.Hole1       
// - Font general (Windows-Fonts)
sTextFont = "Calibri"; // [Arial, Arial Black, Bahnschrift condensed, Calibri, Courier]

/* [Case Feet] */
// - Kind of Case Feet
CaseFeet = 4; // [0:No Feet, 1:OnlyHoles, 2:Rubber Feet, 3:Folding Feet, 4:Folding Feet small]
// - Hole diameter for Case Feet (if not "No Feet")
CaseFeetHole = 3.1;
// - Margin between front panel and Case foot hole
FrontCaseFeetMargin = 7;
// - Margin between back panel and Case foot hole
BackCaseFeetMargin = 10;
// - Margin between left wall and Case foot hole
LeftCaseFeetMargin = 10;
// - Margin between right wall and Case foot hole
RightCaseFeetMargin = 10;

/* [Box Fixation Tabs] */
// - Side screw hole (or snap) diameter (not for inserts)
ScrewHole = 2.2606;
// - Screw thread major diameter for outer shell
BoxHole = 2.8448;
// Thickness of fixation tabs (not for inserts)
TabThick = 2.5;
// use Inserts
// - Varius kinds to fasten the Shells
tab_inserts = 0; //[0:Screws, 1:Snap-tabs EXPERIMENTAL, 2:Insert_M2x4, 3:Insert_M3x5, 4:Insert_M3x6g, 5:Insert_M4x5, 6:Insert_M4x6]
// Back left tab
BLTab = 0; // [0:Bottom, 1:Top]
// Back right tab
BRTab = 0; // [0:Bottom, 1:Top]
// Front left tab
FLTab = 0; // [0:Bottom, 1:Top]
// Front right tab
FRTab = 0; // [0:Bottom, 1:Top]
// EXPERIMENTAL: Snap tabs
SnapTabs = 0; // [0:Screws, 1:Snaps]


/* [PCB Options] */
// - PCB Length
PCBLength = 75.0;
// - PCB Width
PCBWidth = 100.0;
// - PCB Thickness
PCBThick = 1.6;
// You likely need to maintain |TabThick| margin on the left and right for tabs
// and whatnot.
// - Margin between front panel and PCB
FrontEdgeMargin = 25;
// - Margin between back panel and PCB
BackEdgeMargin = 30;
// - Margin between left wall and PCB
LeftEdgeMargin = 10;
// - Margin between right wall and PCB
RightEdgeMargin = 35;
// - Margin between top of PCB and box top
TopMargin = 70;

/* [PCB Feet] */
// - Kind of PCB feet? (x4), No Feet, with Feet, Holes, Spacers or Pillars instead of PCB-Feet
PCBFeet = 1; // [1:with Feet, 0:No Feet, 2:only Holes, 3:Feet w.Insert_M2x4, 4:Feet w.Insert_M3x5, 5:Feet w.Insert_M3x6g, 6:Feet w.Insert_M4x5, 7:Feet w.Insert_M4x6, 8:M3x8_hex_pillar, 9:M3x10_hex_pillar, 10:M3x15_hex_pillar, 11:M3x20_hex_pillar,  12:M3x25_hex_pillar, 13:M4x10_hex_pillar, 14:SPACER_M3x5, 15:SPACER_M3x8, 16:SPACER_M3x10, 17:SPACER_M3x15, 18:SPACER_M3x20, 19:SPACER_M4x5, 20:SPACER_M4x8, 21:SPACER_M4x10, 22:SPACER_M4x15, 23:SPACER_M4x20]
// - Foot height above box interior
FootHeight = 7;
// - Foot diameter
FootDia = 7;
// - Hole diameter, or peg for screwless design, overwritten by choice of PCBFeet
FootHole = 3.0; // [2.0:0.1:4.0]
// - EXPERIMENTAL Screwless design
Screwless = 0; // [0:Screws, 1:Screwless]
FootFilet = FootHeight/4;

// Foot centers are specified as distance from PCB back-left corner.
// X is along the "length" axis, and Y is along the "width" axis.

// - Foot 1, rear left, distance from back PCB edge
Foot1X = 4.2;
// - Foot 1, rear left, distance from left PCB edge
Foot1Y = 3.0;
// - Foot 2, rear right, distance from back PCB edge
Foot2X = 4.2;
// - Foot 2, rear right, distance from right PCB edge
Foot2YFromEdge = 3.0;
Foot2Y = PCBWidth - Foot2YFromEdge;
// - Foot 3, front left, distance from front PCB edge
Foot3XFromEdge = 4.2;
Foot3X = PCBLength - Foot3XFromEdge;
// - Foot 3, front left, distance from left PCB edge
Foot3Y = 3.0;
// - Foot 4, front right, distance from front PCB edge
Foot4XFromEdge = 4.2;
Foot4X = PCBLength - Foot4XFromEdge;
// - Foot 4, front right, distance from right PCB edge
Foot4YFromEdge = 3.0;
Foot4Y = PCBWidth - Foot4YFromEdge;

/* [Frontplate Holes] */
// - Round Holes - [On/Off,xPos,yPos,Diam1,Diam2,Symmetric],[...]
aFP_Holes = [[0,0,0,1,1,0]];
//           

// - Square Holes - [On/Off,xPos,yPos,Width,Hight,Filet],[...]
aFP_SHoles = [[0,10,15,15,10,0]];
//               SquareHole

// - Square Holes with Recess-Margin -[ OnOff, Sx, Sy, Sl, Sw, Recess, XMargin, YMargin],[...]
aFP_SHolesRecess = [[0,9,50,29.5,18,-1.7,1.5,2.0]];
//                   


/* [Frontplate Text] */
// - Round Text [On/Off,xPos,yPos,Fontsize,Diameter,Arc,Start,"Text"],[...]
aFP_RTexts = [[0,122,21,3,10,180,0,"1 . 2 . 3 . 4 . 5 . 6"]];
// - Text  [On/Off,xPos,yPos,Fontsize,"Text"],[...]
aFP_STexts = [[0,50,43,6,"Frontpanel"]];


/* [Backplate Holes] */
// - Square Holes - [On/Off,xPos,yPos,Width,Hight,Filet],[...]
aBP_SHoles = [[0,103,56,19.2,12.9,0]];
//                AC-Power-switch


// - Square Holes with Recess-Margin -[ OnOff, Sx, Sy, Sl, Sw, Recess, XMargin, YMargin],[...]
aBP_SHolesRecess = [[0,66,65,7.0,3.0,1.8,2.7,2.0]];
//                               USB-conn.
// References between USB/BT-switch and its holes
USBcon_LHoleX=aBP_SHolesRecess[0][1]-12.5;
USBcon_RHoleX=aBP_SHolesRecess[0][1]+14.5;
USBcon_HoleY= aBP_SHolesRecess[0][2]-1;

// - Round Holes - [On/Off,xPos,yPos,Diam1,Diam2,Symmetric],[...]
aBP_Holes = [[0,0,0,1.0,1.0,0]];
//             

/* [Backplate Text] */
//Text [On/off,xPos,yPos,Fontsize,"Text"],[...]
aBP_STexts = [[0,65,43,6,"Backpanel"]];
// Round Text [On/off,xPos,yPos,Fontsize,Diameter,Arc,Start,'Text']
aBP_RTexts = [[0,0,0,0,0,0," "]];
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

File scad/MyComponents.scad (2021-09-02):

//
// using NopSCADlib Copyright Chris Palmer 2018
// nop.head@gmail.com
// hydraraptor.blogspot.com
//

// Shows electronic parts for Advanced Ultimate-Box creator

include <NopSCADlib/core.scad>
include <NopSCADlib/vitamins/fans.scad>

use <NopSCADlib/printed/foot.scad>  // for case-feet

// include here additional components which should be displayed


// ***************** insert electronic parts on Front-panel ***************


// ************************************************************************


// *************** insert electronic parts on Back-panel ******************
module ShowFan(Fx, Fy, type) {
 translate([Thick + PanelThickGap + PanelThick,
               Thick + PanelHorizontalGap + PanelWidth,
               Thick + PanelVerticalGap]) {
      rotate([90, 0, 270]) {
         translate([fan_size/2+Fx,fan_size/2+Fy,0]) {
            let($show_threads = true)
            fan_assembly(fans[type], PanelThick, true);
         }
      }
   }

}
// **********************************************************************

// ******************* insert electronic parts inside the box ***********


// **********************************************************************

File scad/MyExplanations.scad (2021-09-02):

module echoPCBFeetDescr() {

   echo();
   echo("***************************************************************");
   echo("                         Explanation for Values PCB-Options");
   echo();
   echo("                                                       Back                                     ");
   echo("                                                             PCBWidth                                           ");
   echo("                    Foot1y |                                                                        | Foot2yEdge");
   echo("                    ______|________________________________________|______");
   echo("                    |          |                                                                        |          |");
   echo("      Foot1x    |          |                                                                        |          | Foot2x");
   echo("               ----|------- O                                                                       O -------|----");
   echo("                    |                                                                                              |");
   echo("                    |                                                                                              |");
   echo("PCBLength     |                                                                                              |");
   echo("                    |                                                                                              |");
   echo("                    |                                                                                              |");
   echo("                    |                                                                                              |");
   echo("                    |                                                                                              |");
   echo("               ----|------- O                                                                       O -------|----");
   echo("                    |          |                                                                        |          |");
   echo("  Foot3xEdge |           |                                                                        |         |");
   echo("                     ______|________________________________________|_____");
   echo("                                |                                                                       |          ");
   echo("                    Foot3y  |                                                                       |  Foot4yEdge ");
   echo("                                                      Front                                              ");
   echo();
   echo("********************************************************************");
   echo();
   
   

}

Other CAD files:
assemblies/FoldingFoot-base.step
assemblies/FoldingFood-base-small.FCStd
stls/FoldingFoot-base-small.stl
Examples/Mini-PowerSupply/stls/FoldingFoot-arm.stl
stls/FoldingFoot-arm.stl
scad/MyInserts.scad
Examples/Mini-PowerSupply/assemblies/AutomFuseholder.FCStd
Examples/Mini-PowerSupply/assemblies/AutomFuseholder.amf
Examples/Mini-PowerSupply/assemblies/AutomFuseholder.f3d
Examples/Mini-PowerSupply/assemblies/AutomFuseholder.step
Examples/Mini-PowerSupply/assemblies/AutomFuseholder.stl
Examples/Mini-PowerSupply/assemblies/BATTERY-HOLDER_18650.stl
Examples/Mini-PowerSupply/assemblies/BT-Modul_BK3231.amf
Examples/Mini-PowerSupply/assemblies/BT-Modul_BK3231.f3d
Examples/Mini-PowerSupply/assemblies/BT-Modul_BK3231.step
Examples/Mini-PowerSupply/assemblies/DPDT_Slide_Switch.amf
Examples/Mini-PowerSupply/assemblies/DPDT_Slide_Switch.f3d
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

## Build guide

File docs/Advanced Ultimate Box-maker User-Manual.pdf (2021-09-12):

# Electronic design

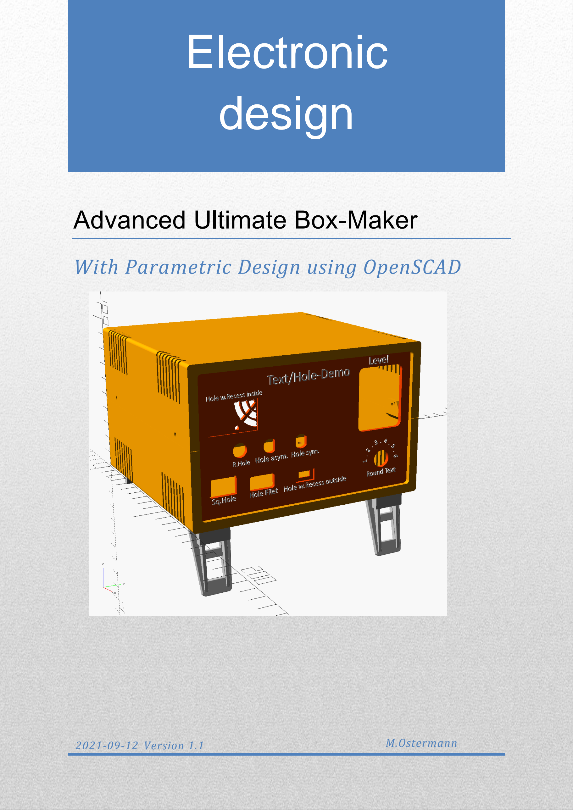
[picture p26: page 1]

User Part of „Advanced Ultimate Box-Maker”

# Advanced Ultimate Box-Maker

# With Parametric Design using OpenSCAD

2021-09-12 Version 1.1

M.Ostermann

# Advanced Ultimate Box-Maker

## Table of contents

Introduction | 0
Originally box designs, used libraries, license | 0
User Part of the “Advanced Ultimate Box-Maker” | 0
Installation | 0
Features | 0

Summary of Existing Features which the original version and the improved
version have | 0
Added more features, list of the most important ones | 1
Handling the program | 1
Sections and values | 1
Explanation of the most important values | 2
Explanation of program-parts | 0
Connection between the box-program and the lib “NopSCADlib” | 0
Fansize and screw-distance | 0
Feet for PCB | 0
Additional holes | 1
Box fixation tabs | 1
Long holes | 1
Square Holes with a Recess | 1
Case-Feet | 2

Introduction

## Introduction

For my projects in electronics I often need an appropriate housing.
Commercial products have the disadvantage that they don’t fit exactly and cause a lot of work for manual drilling, cutting, adapting, etc.
I needed a software solution for creating an individual box using a 3D-printer.
- The software must have mainly a parametric design so that the properties of the box can be easily changed.
- The software must have a GUI for changing the parameters so that the program code does not need to be changed.
- Ideally the software allows to save the parameters in individual files.
The software with the less disadvantages I could find, was OpenSCAD.
It is relatively easy to learn and has a so called customizer for changing and saving the parameters. But it has also a lot of restrictions to deal with. Despite this OpenSCAD was the first choice. My normally used CAD-Software “Fusion-360” is nice to use but has only a bit of a customizer.

For that reason, the decision was using OpenSCAD and I searched around which programs exists to solve my problem.

I found the “Ultimate Box Maker” with its forks and put me on to extend the features of these programs with help of some excellent libraries.
The result is this “Advanced Ultimate Box Maker”.

Originally box designs, used libraries, license
- Programs are under license CC BY-NC 3.0 License and GNU General Public License 3
- The original design was by “Ultimate Box Maker” from Heartman www.thingiverse.com/thing:1264391 and http://heartygfx.blogspot.com
- The great improvement to a PCB-based construction was the “Customizable revised Ultimate Box Maker” from jbebel www.thingiverse.com/thing:2938921 and https://github.com/jbebel/Ultimate-Box-Maker.
- I was inspired for the fan-part by the “Customizable Fan Grill Cover” from mightynozzle www.thingiverse.com/thing:2802474
- Library “BOSL2” from https://github.com/revarbat/BOSL2/
- Library “NopSCADlib” from https://github.com/nophead/NopSCADlib/

User part of the “Advanced Ultimate Box-Maker”

## User Part of the “Advanced Ultimate Box-Maker”

Description of the features, the installation and how to use the software

Installation
You need the following parts
- OpenSCAD, from https://openscad.org/downloads.html. download and install the exe-file.
- The library “BOSL2” from https://github.com/revarbat/BOSL2/
unpack the zip-file into the appropriate lib-directory (My Documents\OpenSCAD\libraries)
- The library “NopSCADlib” from https://github.com/nophead/NopSCADlib unpack the zip-file into the appropriate lib-directory (My Documents\OpenSCAD\libraries)
- The actually “Advanced ultimate Box Maker” from https://github.com/moster/Avanced-Ultimate-Box-Maker
Unpack the zip-file into the directory My Documents\OpenSCAD
so that all files are in the sub-directory \Advanced-Ultimate-Box-Maker

To check the installation, run the main-file “Advanced-Ultimate-Box-Makermain.scad”, and press F5 to create the box.

Features

Summary of Existing Features which the original version and the improved version have
- Editable back- and front panel
- Calculation of the box size from the PCB size and margin parameters
- Horizontal or vertical text alignment arguments
- Variable panel and tab thickness separate from the box
- Square corners (no filet or chamfer)
- Parameterize all dimensions, such that the box is infinitely scalable. Doubling every parameter will double the box in all dimensions.
- Vents go through the floor and are scaled to fit the size of the filet.
- For larger filets, scale interior filets to make exterior and interior filets concentric.
- Decorations are optional
- Box fixation tabs can individually be placed on the top or bottom shell

Added more features, list of the most important ones
- Allows to integrate the electronic parts of the NopSCAD-lib
- Choice of different case feet
- Choice of different threated inserts for fixation tabs
- Choice of different kind of PCB-feet (inserts, pillars, spacers)
- Holes with a recess for front- or backpanel
- Longholes for front- or backpanel
- Customizable fan-guard for the backpanel
- Usual fan sizes are integrated and the correct screw-distance is autom. choosen.
- Ledges on both upper edges of the box shells for better stabilization
- Allows to create extra holes in the bottom shell
- Choose predefined font for paneltext
- Frequent remarks added in the code and a lot of debug outputs

With this advanced version the number of program lines has grown from round about 900 to more than 1800 lines.

Handling the program
After starting OpenSCAD, you see the customizer on the right side with the various program values categorized in sections.
Click the center symbol | to view the whole box

Sections and values
Sections and values in the customizer on the right side
| These sections include several parametric values to adapt the box to your requirements in an easy way

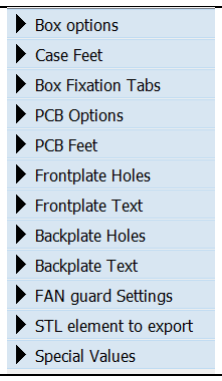
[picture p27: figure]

Same values are on the left side in the editor window

Kind of values in the customizer
| Arrays, beginning with “a..”: Cannot be changed in customizer. MUST be changed in the editor window on the left side because of the customizers restrictions.

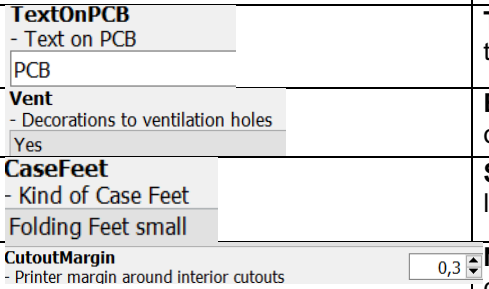
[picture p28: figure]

| Textbox, sets a text. f.e. a text on top of the PCB. Change in customizer.
| Boolean Value, activates/deactivates an option. Change in customizer.
| Selection, selects a value out of a given list.
| Numeric value, can be changed in customizer. Change in customizer.

All values, with exception of the arrays, can be saved in a configuration-file on top of the customizer window. The arrays must be saved with the complete scad-file (i.e. changing of the code)

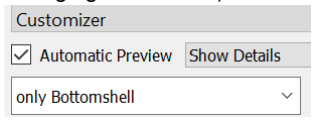
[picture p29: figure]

One member is the minimum for an array, otherwise the program throws an error. If the part is not used, array-members can be deactivated when On/Off is set to “0”.

Explanation of the most important values
Section “box options”
PCBDraw, draws the PCB inside the box and labels it with the text of “TextOnPCB”. Only one PCB possible.

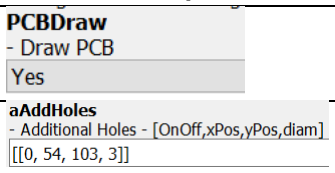
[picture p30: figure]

Array must be edited in code window. For manual ading holes in the bottom shell for additional PCBs f.e.

Draws electr. Parts with help of the NopSCADlib. Parts must be defined in “MyComponents.scad”, imported then positioned in Module “ShowElectrParts”.

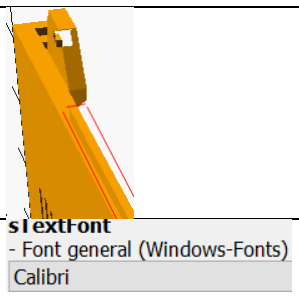
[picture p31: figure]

Bar recess, can be activated/deactivated. When Thick <2.5mm, recess is autom. deactivated because it cannot be printed.

Selection of the font for text on panels. List contains windows-fonts and can be changed in code window. Font names must fit to the name in windows.

Section “case feet”
Various feet can be chosen, simple hole, rubber feet, foldable feet in 2 sizes. The last both are created as stl-files and can be 3D-printed.

Section “Box Fixation Tabs” Various kinds, from simple holes for screws to threaded inserts

Section “PCB Options”
With defining these variables the dimensions of the box are autom. calculated. The value “TopMargin” defines in result the hight of the box.
The console window shows the resulting dimensions of the box.

Section “PCB Feet”
| Various kinds of PCB-feet, from simple holes for screws to holes with threaded inserts. All dimensions are autom. adapted.
Coord. Of the 4 PCB-feet | The console window shows the resulting distances of the PCB-feet to prove the correct values of the PCB-holes.

If you enable “ShowExplanations” in the section ”Special Values”, the console window shows the position of the 4 PCB-feet.

Section “Frontplate Holes”
The variables within this section define 3 kind of holes.
All these hole-parameters are Arrays and must be changed in the code window, not in the customizer.
aFP_Holes | Defines round holes or longholes There are 2 diams, diam1 and diam2. If both are equal, the result is a round hole. If diam1 > diam2 the result is a longhole If sym=0, the hole is narrower on the right side. If sym=1, the hole is narrow on left ans right side
aFP_Sholes | Defines square holes
aFP_SHolesRecess | Defines a recess of PanelThick minus Recess. If Recess is positiv, its on the outer side. if recess is negativ, its on the inner side.

Section “Frontplate Text”
There are 2 kind of Texts: Normal text and round text.
All these hole-parameters are Arrays and must be changed in the code window, not in the customizer.
aFP_RTexts | Defines round text. F.e. useful for labeling Poti-values
aFP_STexts | Defines normal text

Section “Backplate Holes”, same as for Frontplate Holes

Section “Backplate Text”, same as for Frontplate Text

Section “Fan-guard settings”, implemented only for the Backplate
BP_fan_position | Pos. of the fan-guard,can be activated by On/off-value set to “1”
Fan_size_in_mm | Dim. of fans are integrated in an array. When selecting a size, all parameters are calculated autom.
Screw_hole_diameter | Diam. of the screw between M2-M4
Fan_min_border_size | Try out the best fitting values. But the simplest way is
Fan_line_size | not to change them.
Fan_line_space
Number_of_support_lines | Number of crosshairs of the fan-guard, 4 is a good
| value.

Section “STL-element to export”
These Boolean values determine which part should be printed. It makes sense to enable only one part at a time.
With keys F5, then F6, you can render a part for STL-Export.
Export the part with key F7 and save it as STL-file.
TShell | Top shell of the box
BShell | Bottom shell of the box
FPanl | Frontpanel
BPanel | Backpanel
SmallParts | Small assembly-parts which should be printed. It depends what you have choosen, F.E. It can be spacers for the PCB.

Section “Special values”
ShowExplanations | Self defined echo-outputs in the console-window. They are defined in the “MyExplanations.scad” file. F.E. the position of the 4 PCB-feet
Debug | When “1”, there is a lot of echo output from program-values. For easier assignment, the output has format:: <mod.:> from which module the output comes <description:> name of the variable or its description <value> the value itself of the var

Explanation of program-parts

## Explanation of program-parts

The most important parts for better orientation with their line numbers in brackets

Connection between the box-program and the lib “NopSCADlib”
Its possible to use this library to insert electronic parts in the design of the box for better illustrating and checking the dimensions. These parts are only visible in preview-mode (<F5>) because it makes no sense to create stl-files from that parts.

The use of elements in the NopSCADLib” are all similar structured. On the upper level is a definition-file which presets the dimensions, position and other values for an object.
The second level is a second file which draws this object.
For example the file “Inserts.scad” contains several types of threaded inserts.
This module calls the actual part in another file named ”insert.scad”.
The description files with several types are named in plural, the files for drawing the object are named in singular.
This has the advantage to separate the drawing from the definition of an object. And this makes possible to use own definition files in an easy way without need to change the library code.
The files “My..” in the program folder are self-created definition files for that purpose.

The import takes place over several layers:
- The module “ShowElectrParts (L.1715) in the Main-program makes call of a part
- Module with Electronic part in “MyComponents.scad”
there are all electr. parts listed, for each part an own module
this layer abstracts the definitions and values to follow on the next layer
- Call of the drawing part itself in the NopSCADLib/vitamins directory

Fansize and screw-distance
The size of a fan is predefined in a selection field “fan_size_in_mm” in the customizer area. (L.258)
This field is a list of fans with the dimension. The choice of a fan in the list results in an index-value. F.e. the fan with dim. 40mm results in an index with value “2”.
The according srew-distance of the choosen fan is calculated from line (329) with the array “aPos” and the fan-type.

Feet for PCB
The module “Feet” (L.913) is upgraded to make it possible to use spacers, hexpillars. With help of the resulting index of the choosen feet-type the appropriate part is called within the “nopSCADlib”.
When inserts are choosen, the correct hole-diameter of the pcb-feet is calculated.

Explanation of program-parts

The dimensions of the inserts are defined in the file “MyInserts.scad”.

Additional holes
Within this concept of this program it is only possible to use 1 PCB.
In the array “aAddHoles” (L.111) can be defined more holes to make it possible to implement a 2nd. PCB.
Additional holes can only be defined for the bottom shell not for the top shell. Otherwise it would be the case that the add. holes in the bottom shell are also in the top shell because the top shell is a mirror the bottom one.

Box fixation tabs
The fixation tabs “tab_inserts” (L.139) were upgraded for the use of threaded inserts. The resulting value for the index is evaluated in (L.348) and presets the correct value for the tab-hole in module “Tabs” (L.720)

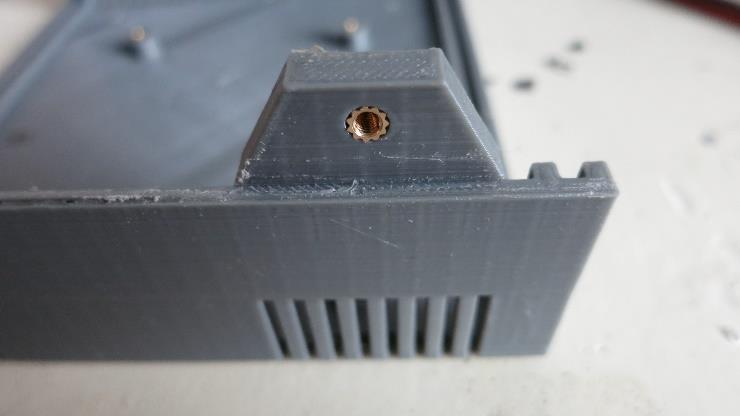
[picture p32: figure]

Long holes
There are some parts like powerplugs or powerjacks which need long holes.
The flattening of the hole can be on the right side or on both sides.
For easier coding the arrays aFP_Holes and aBP_Holes have been extended by a 2

nd diameter “diam2” to define the second value for this long hole. For that the last parameter “symmetric” in the array must set to”1”.
To create a normal hole, the values for “diam1” and “diam2” must be equal. “diam1” must be greater than “diam2”.

Square Holes with a Recess
Sometimes is the need of holes with a recess. That can be necessary on the outer side for an usb-connector or on the inner side of a panel for a LED-Display.
The code for a recess is implemented only for a square hole.
The definition of the parameters is in arrays “aFP_SHolesRecess” and “aBP_SHolesRecess”. (L.219 and L.237).
The programm sequence is similar to that of normal holes.
The modules “FPanelHolesRecess” (L.449) and “BPanelHolesRecess” (L.495) evaluate the elements of the arrays and pass them on to the module “SquareHoleRecess” (L.1378) which creates the hole(s).

Explanation of program-parts

Case-Feet
With the options in the field for case feet it is possible to choose two sizes of feet which can be fold up.

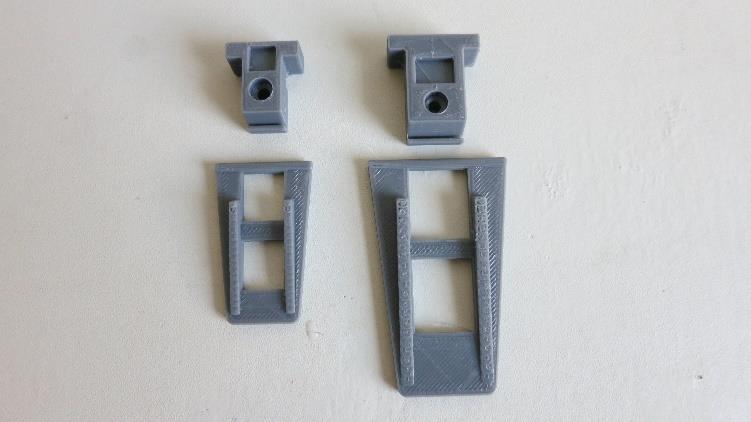
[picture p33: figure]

The definition of the feet is in “CaseFeet” (L.119)
The feet consist of 2 parts: the base-part and the arm.
For easier handling the foot has been created in Fusion and can be direct printed using the stl-files in the subdirectory “stls”. The source design file for the feet is in the directory “assemblies”.

To prevent the powersupply form sliding over the ground the some rubber-feet can be added into the recess of the foldable feet.


But it must be self-adhesive rubber material not spongue rubber. That’s too soft.

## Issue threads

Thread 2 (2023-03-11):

Unknown module 'DrawBattHolder'

mklengel, 2023-03-11:
Opening Advanced-Ultimate-Box-Maker-main.scad and setting SmallParts=yes (Customizer) leads to:

`WARNING: Ignoring unknown module 'DrawBattHolder' in file Advanced-Ultimate-Box-Maker-main.scad, line 1780`

M-oster, 2023-03-12:
Oh, thanks for the hint. You can delete this part of  4 lines at the end of the main-script. That belongs to the expample with the mini-powersupply. DrawBattholder is referenced in Mycomponents.scad. But an empty case has no components inside and of cause no Batteryholder.

Closed 2023-03-12.

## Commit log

2021-09-02 Mobile Powersupply
    [Adv-Ultimate-Box-PowerSupply-Backpanel.stl, Adv-Ultimate-Box-PowerSupply-BottomShell.stl, Adv-Ultimate-Box-PowerSupply-Frontpanel.stl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]
2021-09-03 update BOM
2021-09-05 Delete ShowBatteryMeter.scad
    deleted
    [ShowBatteryMeter.scad]
2021-09-06 Create Mobile Mini-Powersupply KiCad schematic.zip
    KiCad Schematic
2021-11-03 fixed
    issue fixed because of changed BOSL2 lib
    [Adv-Ultimate-Box-PowerSupply-main.scad, Advanced-Ultimate-Box-Maker-DimDemo.scad, Advanced-Ultimate-Box-Maker-Holes_TextsDemo.scad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]
